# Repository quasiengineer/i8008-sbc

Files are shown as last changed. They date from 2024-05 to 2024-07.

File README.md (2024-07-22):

# System board for Intel 8008

Video about this project:
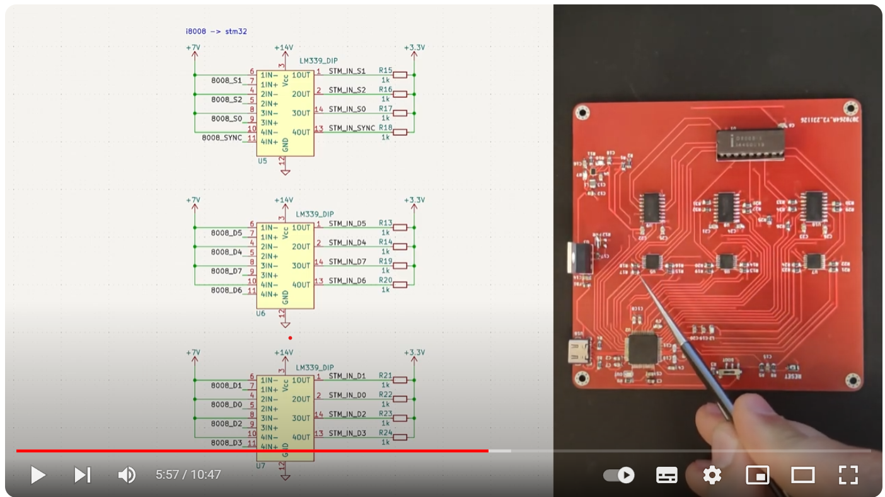
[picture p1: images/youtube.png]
Video about this project (https://www.youtube.com/watch?v=hh_iSX-aM4Q "Video about this project")


## Board

Schematics in [pdf format](./pcb/schematic.pdf)

schematic

Archive with gerber files and drill locations could be found [here](./pcb/manufacturing/manufacturing.zip)

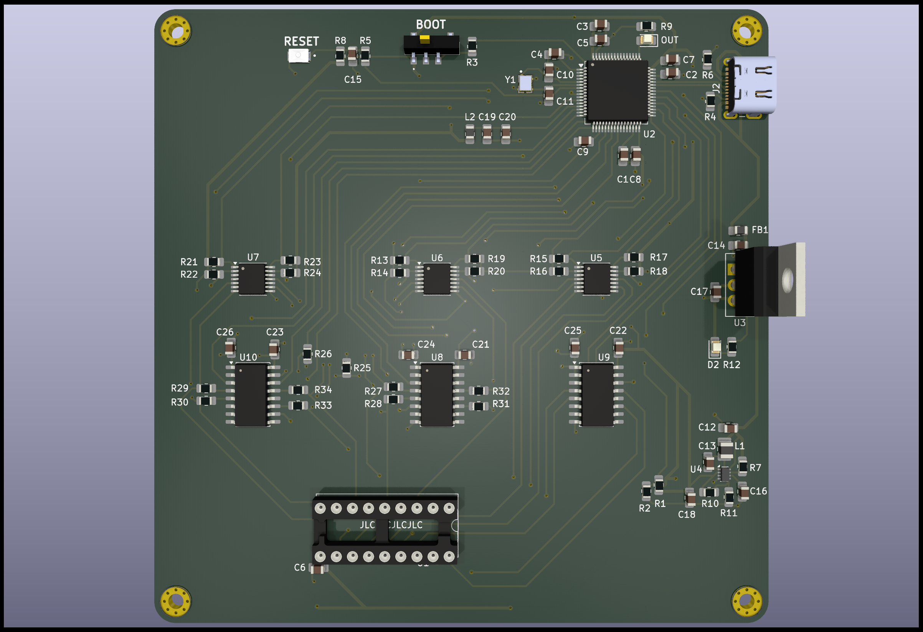
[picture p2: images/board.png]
pcb


Bill of material in [CSV format](./pcb/i8008-sbc.csv)

|Reference |Value |Qty|Mouser Part Number  |
|---|---|---|---|
|C4,C5,C6,C7,C8,C9,C13,C15,C20,C21,C22,C23,C24,C25,C26|100n |15 |187-CL21B104KACNFNC |
|R13,R14,R15,R16,R17,R18,R19,R20,R21,R22,R23,R24 |1k |12 |603-RT0805FRE071KL  |
|R5,R27,R28,R29,R30,R31,R32,R33,R34 |220 |9  |603-RT0805FRE10220RL|
|R1,R2,R3,R8,R25,R26 |10k |6  |603-RT0805FRE1310KL |
|U8,U9,U10 |CD40109B |3  |595-CD40109BNSR |
|U5,U6,U7 |LM339_DIP |3  |595-LM339APWR |
|C14,C16,C19 |1u |3  |187-CL21B105KOFNNNE |
|R7,R11 |30k |2  |603-RT0805FRE0730KL |
|R4,R6 |5k1 |2  |603-RT0805FRE075K1L |
|C17,C18 |10u |2  |810-C2012JB1C106M08C|
|C10,C11 |10p |2  |710-885012007010 |
|C3,C12 |4u7 |2  |810-C2012X5R1C475M0B|
|C1,C2 |2u2 |2  |187-CL21A225KAFNNNG |
|Y1 |16Mhz |1  |520-160-10-36CKM-TR3|
|U4 |MP3438 |1  |946-MP3438GTL-P |
|U3 |LM2937xT |1  |926-LM2937ET-3.3NOPB|
|U2 |STM32H7A3RGTx |1  |511-STM32H7A3RGT6 |
|U1 |Intel 8008 |1  |571-1-2199298-5 |
|SW2 |RESET |1  |667-EVP-AWED4A |
|SW1 |BOOT |1  |113-SS3PMVT/R |
|R12 |2k2 |1  |603-RT0805FRE072K2L |
|R10 |390k |1  |603-RT0805FRE07390KL|
|R9 |4k7 |1  |603-RT0805FRE074K7L |
|L2 |27n |1  |652-CE201210-27NJ |
|L1 |8u2, 800mA |1  |652-SRR1280-8R2Y |
|J2 |Type-C |1  |656-DX07S016JA1R1500|
|FB1 |FerriteBead_Small|1  |652-MH2029-101Y |
|D2 |Green |1  |710-150080VS75000 |
|D1 |Red |1  |710-150080RS75000 |

Also you can find prepared Mouser project [here](https://www.mouser.com/ProjectManager/ProjectDetail.aspx?AccessID=507c82b5f1).

## Firmware

There is compiled [hex file](./firmware/bin/i8008-sbc.hex) in repository, that could be flashed to PCB.

Make sure that `BOOT` switch lever shifted in direction of `RESET` button and connect the board via USB and use stm32 programming software. I am using stm32programmer.

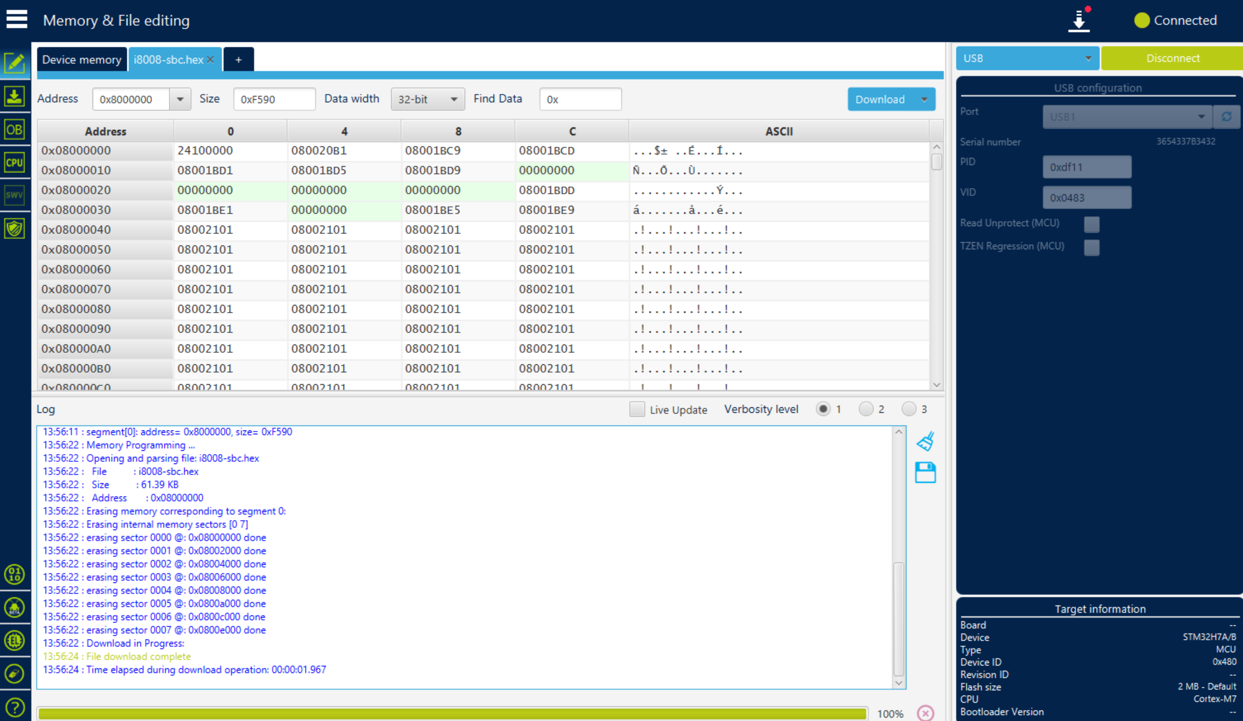
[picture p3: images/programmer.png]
programming


## Software

Make sure that `BOOT` switch lever shifted in direction of stm32 MCU and connect the board via USB.

Red LED should be lighting and new terminal COM device should appear in the system.

To actually run a program in 8008 you just need to run single command:
```sh
node index.js -port=COM5 -rom="programs/blank.i8008"
```

Where `COM5` is the port name. And ROM is the path for program to be run.

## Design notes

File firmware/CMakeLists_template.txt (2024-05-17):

#${templateWarning}
set(CMAKE_SYSTEM_NAME Generic)
set(CMAKE_SYSTEM_VERSION 1)
${cmakeRequiredVersion}
# specify cross-compilers and tools
set(CMAKE_C_COMPILER arm-none-eabi-gcc)
set(CMAKE_CXX_COMPILER arm-none-eabi-g++)
set(CMAKE_ASM_COMPILER  arm-none-eabi-gcc)
set(CMAKE_AR arm-none-eabi-ar)
set(CMAKE_OBJCOPY arm-none-eabi-objcopy)
set(CMAKE_OBJDUMP arm-none-eabi-objdump)
set(SIZE arm-none-eabi-size)
set(CMAKE_TRY_COMPILE_TARGET_TYPE STATIC_LIBRARY)

# project settings
project(${projectName} C CXX ASM)
set(CMAKE_CXX_STANDARD 17)
set(CMAKE_C_STANDARD 11)

#Uncomment for hardware floating point
#add_compile_definitions(ARM_MATH_CM4;ARM_MATH_MATRIX_CHECK;ARM_MATH_ROUNDING)
#add_compile_options(-mfloat-abi=hard -mfpu=fpv4-sp-d16)
#add_link_options(-mfloat-abi=hard -mfpu=fpv4-sp-d16)

#Uncomment for software floating point
#add_compile_options(-mfloat-abi=soft)

add_compile_options(-mcpu=${mcpu} -mthumb -mthumb-interwork)
add_compile_options(-ffunction-sections -fdata-sections -fno-common -fmessage-length=0)

# uncomment to mitigate c++17 absolute addresses warnings
#set(CMAKE_CXX_FLAGS "$${CMAKE_CXX_FLAGS} -Wno-register")

# Enable assembler files preprocessing
add_compile_options($<$<COMPILE_LANGUAGE:ASM>:-x$<SEMICOLON>assembler-with-cpp>)

if ("$${CMAKE_BUILD_TYPE}" STREQUAL "Release")
    message(STATUS "Maximum optimization for speed")
    add_compile_options(-Ofast)
elseif ("$${CMAKE_BUILD_TYPE}" STREQUAL "RelWithDebInfo")
    message(STATUS "Maximum optimization for speed, debug info included")
    add_compile_options(-Ofast -g)
elseif ("$${CMAKE_BUILD_TYPE}" STREQUAL "MinSizeRel")
    message(STATUS "Maximum optimization for size")
    add_compile_options(-Os)
else ()
    message(STATUS "Minimal optimization, debug info included")
    add_compile_options(-Og -g)
endif ()

include_directories(${includes})

add_definitions(${defines})

file(GLOB_RECURSE SOURCES ${sources} "App/*.*")

set(LINKER_SCRIPT $${CMAKE_SOURCE_DIR}/${linkerScript})

add_link_options(-Wl,-gc-sections,--print-memory-usage,-Map=$${PROJECT_BINARY_DIR}/$${PROJECT_NAME}.map)
add_link_options(-mcpu=${mcpu} -mthumb -mthumb-interwork)
add_link_options(-T $${LINKER_SCRIPT})

add_executable($${PROJECT_NAME}.elf $${SOURCES} $${LINKER_SCRIPT})

set(HEX_FILE $${PROJECT_BINARY_DIR}/$${PROJECT_NAME}.hex)
set(BIN_FILE $${PROJECT_BINARY_DIR}/$${PROJECT_NAME}.bin)

add_custom_command(TARGET $${PROJECT_NAME}.elf POST_BUILD
        COMMAND $${CMAKE_OBJCOPY} -Oihex $<TARGET_FILE:$${PROJECT_NAME}.elf> $${HEX_FILE}
        COMMAND $${CMAKE_OBJCOPY} -Obinary $<TARGET_FILE:$${PROJECT_NAME}.elf> $${BIN_FILE}
        COMMENT "Building $${HEX_FILE}
Building $${BIN_FILE}")

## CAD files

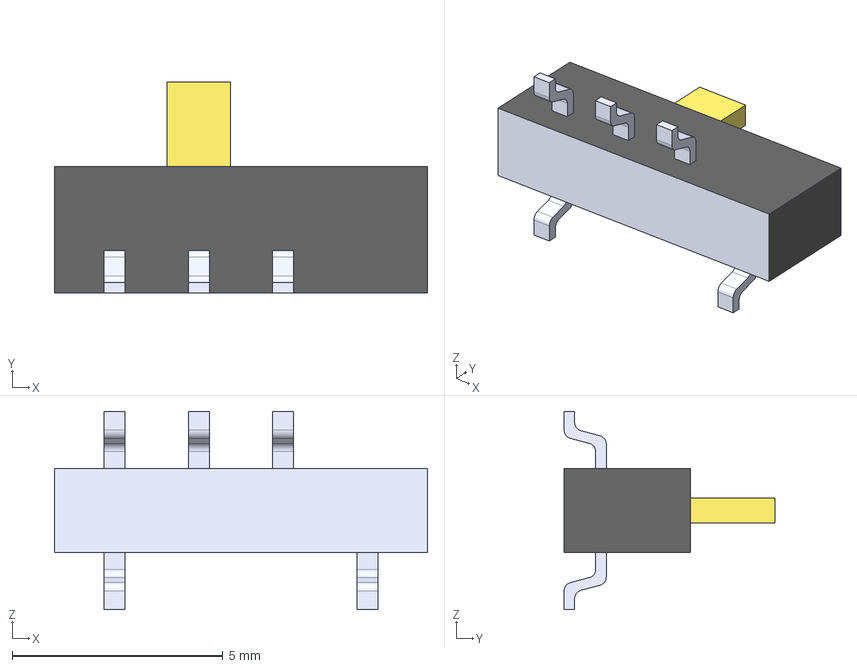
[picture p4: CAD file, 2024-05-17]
pcb/components/3d/SS3NP-MS-colors.STEP
8.85 x 5.00 x 4.70 mm
SS3NP-MS
SS3NP-MS001
SS3NP-MS002
SS3NP-MS003
SS3NP-MS004
SS3NP-MS005
SS3NP-MS006

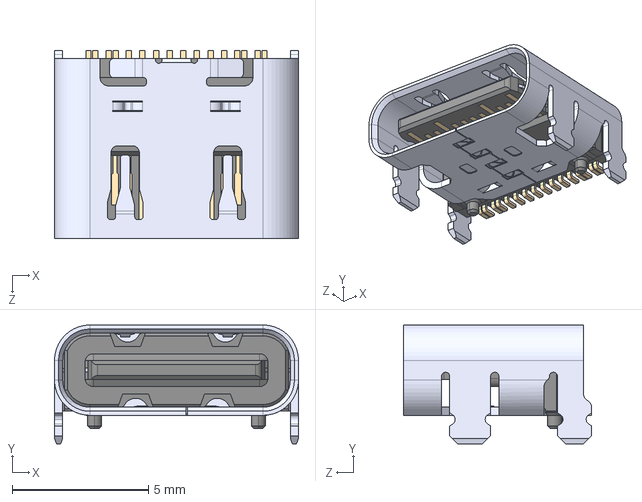
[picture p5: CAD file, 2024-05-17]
pcb/models/DX07S016JA1R1500.stp
8.94 x 4.36 x 6.90 mm

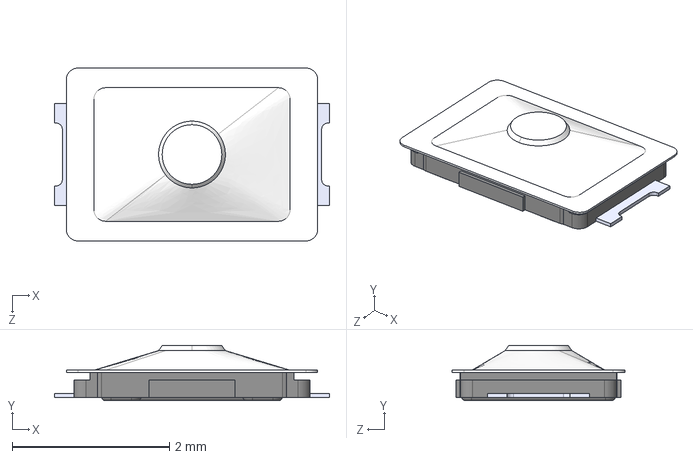
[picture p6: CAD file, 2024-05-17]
pcb/components/3d/EVP-AWED4A.step
3.50 x 0.7 x 2.20 mm

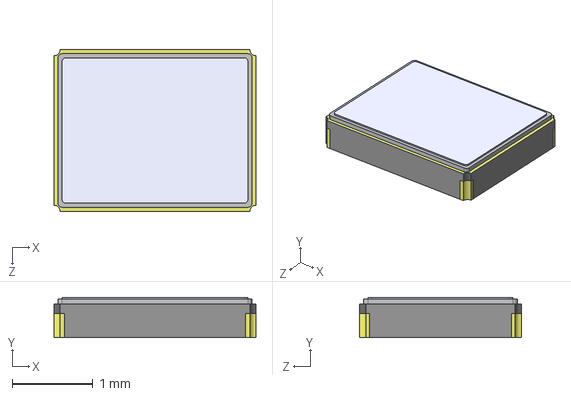
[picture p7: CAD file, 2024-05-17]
pcb/components/3d/ECS-160-10-36-CKM-TR3.step
2.50 x 0.5 x 2.00 mm

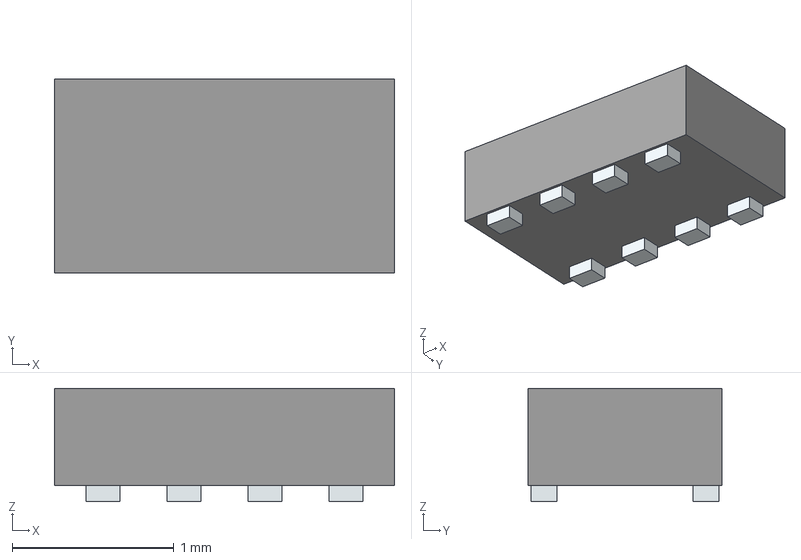
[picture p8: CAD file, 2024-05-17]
pcb/components/3d/MP3438GTL-P.stp
2.10 x 1.20 x 0.7 mm
Pins

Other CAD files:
pcb/components/3d/SS3NP-MS.SLDPRT

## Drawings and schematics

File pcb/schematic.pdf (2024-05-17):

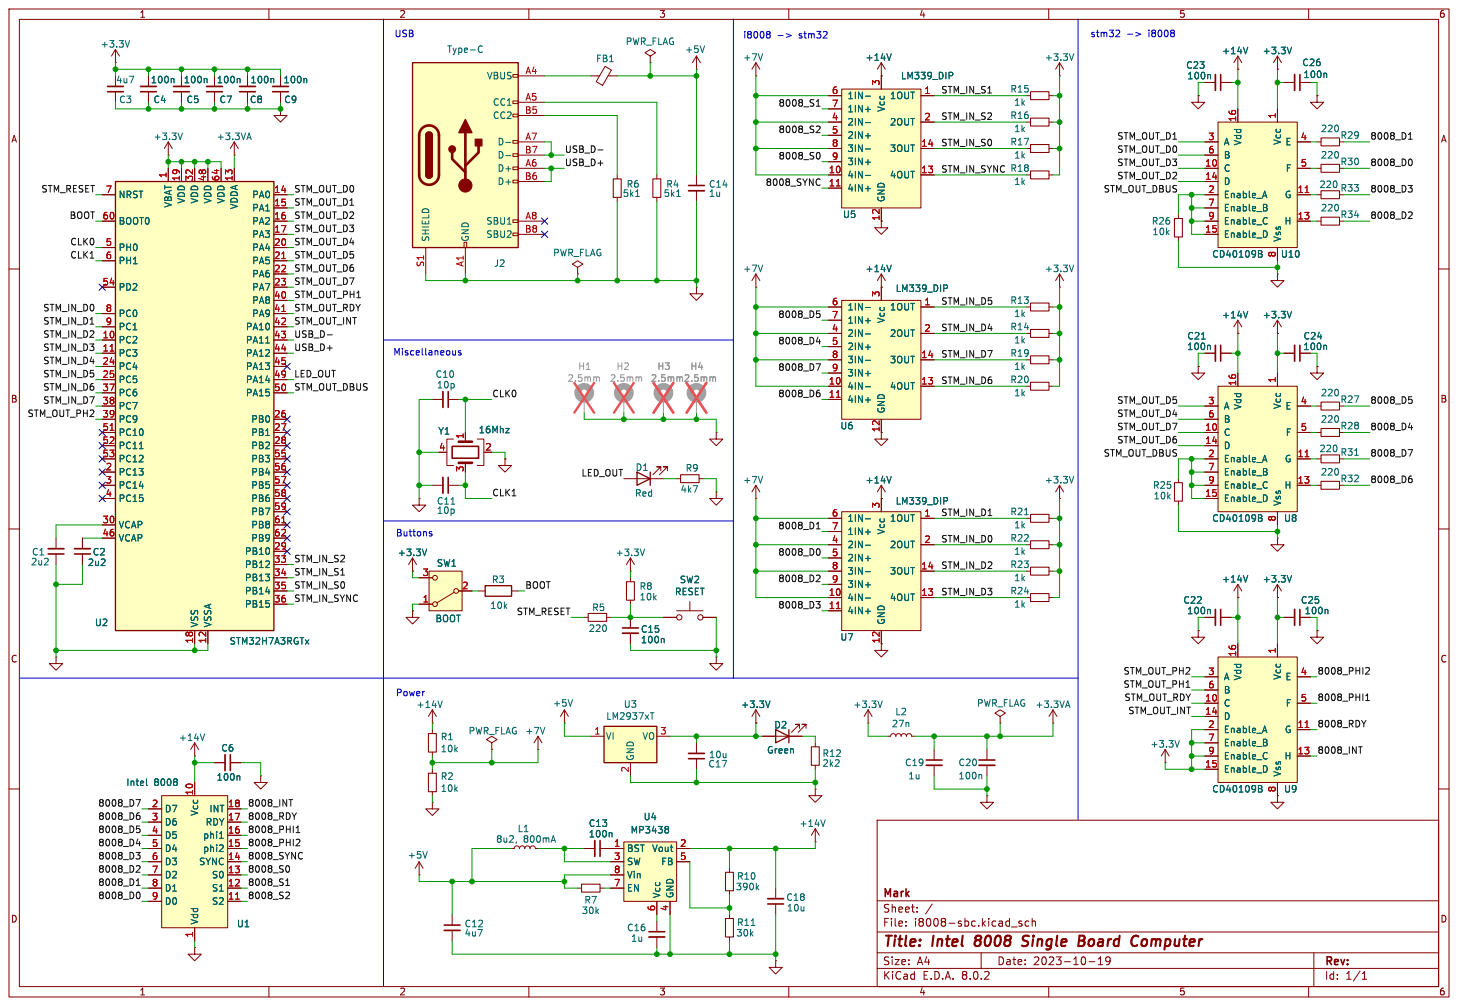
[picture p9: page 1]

1 PC2 10 PC3 11 VSSA 12 VDDA 13 PA0 14 PA1 15 PA2 16 PA3 17 VSS 18 VDD 19 PC13 2 PA4 20 PA5 21 PA6 22 PA7 23 PC4 24 PC5 25 PB0 26 PB1 27 PB2 28 PB10 29 PC14 3 VCAP 30 VDD 32 PB12 33 PB13 34 PB14 35 PB15 36 PC6 37 PC7 38 PC9 39 PC15 4 PA8 40 PA9 41 PA10 42 PA11 43 PA12 44 PA13 45 VCAP 46 VDD 48 PA14 49 PH0 5 PA15 50 PC10 51 PC11 52 PC12 53 PD2 54 PB3 55 PB4 56 PB5 57 PB6 58 PB7 59 PH1 6 BOOT0 60 PB8 61 PB9 62 VDD 64 NRST 7 PC0 8 PC1 9 C9

1 PC2 10 PC3 11 VSSA 12 VDDA 13 PA0 14 PA1 15 PA2 16 PA3 17 VSS 18 VDD 19 PC13 2 PA4 20 PA5 21 PA6 22 PA7 23 PC4 24 PC5 25 PB0 26 PB1 27 PB2 28 PB10 29 PC14 3 VCAP 30 VDD 32 PB12 33 PB13 34 PB14 35 PB15 36 PC6 37 PC7 38 PC9 39 PC15 4 PA8 40 PA9 41 PA10 42 PA11 43 PA12 44 PA13 45 VCAP 46 VDD 48 PA14 49 PH0 5 PA15 50 PC10 51 PC11 52 PC12 53 PD2 54 PB3 55 PB4 56 PB5 57 PB6 58 PB7 59 PH1 6 BOOT0 60 PB8 61 PB9 62 VDD 64 NRST 7 PC0 8 PC1 9 U2 STM32H7A3RGTx

4 FB 5 Vcc 6 EN 7 Vin 8 SW1 BOOT

4 FB 5 Vcc 6 EN 7 Vin 8 U4 MP3438 C16

Id: 1/1 Title: Intel 8008 Single Board Computer File: i8008-sbc.kicad_sch Sheet: / Mark

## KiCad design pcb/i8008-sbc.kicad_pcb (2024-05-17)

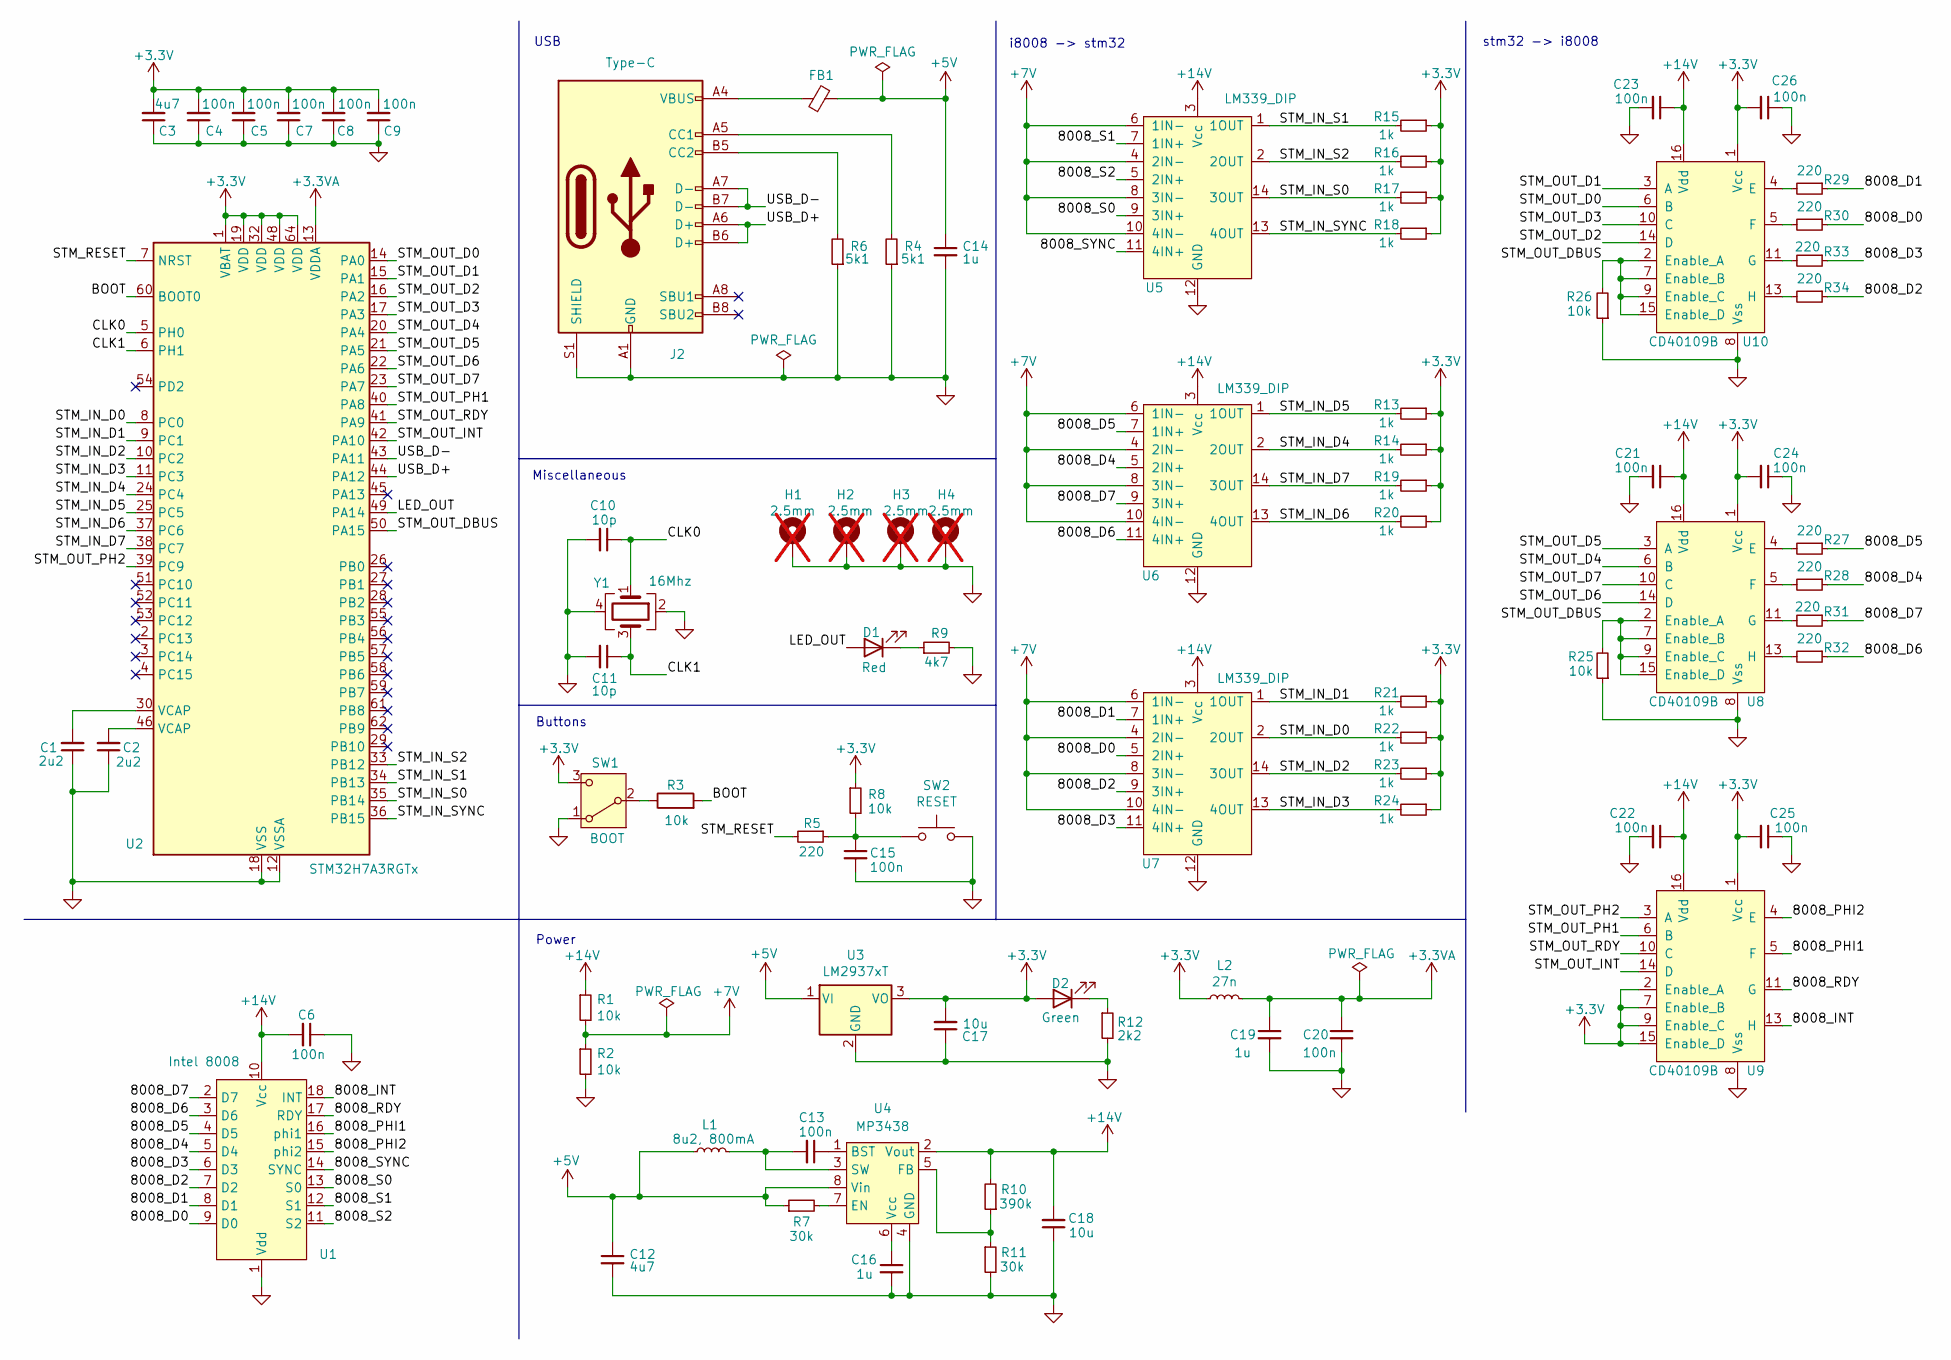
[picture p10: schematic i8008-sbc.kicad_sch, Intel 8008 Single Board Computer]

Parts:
C1, C2: 2u2; C_0805_2012Metric_Pad1.18x1.45mm_HandSolder; Mouser Part Number 187-CL21A225KAFNNNG
C3, C12: 4u7; C_0805_2012Metric_Pad1.18x1.45mm_HandSolder; Mouser Part Number 810-C2012X5R1C475M0B
C4, C5, C6, C7, C8, C9, C13, C15, C20, C21, C22, C23, C24, C25, C26: 100n; C_0805_2012Metric_Pad1.18x1.45mm_HandSolder; Mouser Part Number 187-CL21B104KACNFNC
C10, C11: 10p; C_0805_2012Metric_Pad1.18x1.45mm_HandSolder; Mouser Part Number 710-885012007010
C14, C16, C19: 1u; C_0805_2012Metric_Pad1.18x1.45mm_HandSolder; Mouser Part Number 187-CL21B105KOFNNNE
C17, C18: 10u; C_0805_2012Metric_Pad1.18x1.45mm_HandSolder; Mouser Part Number 810-C2012JB1C106M08C
D1: Red; LED_0805_2012Metric_Pad1.15x1.40mm_HandSolder; Mouser Part Number 710-150080RS75000
D2: Green; LED_0805_2012Metric_Pad1.15x1.40mm_HandSolder; Mouser Part Number 710-150080VS75000
FB1: FerriteBead_Small; L_0805_2012Metric_Pad1.15x1.40mm_HandSolder; Mouser Part Number 652-MH2029-101Y
H1, H2, H3, H4: 2.5mm; MountingHole_2.5mm_Pad_Via; not fitted
J2: Type-C; USB_C_Receptacle_JAE_DX07S016JA1R1500; Mouser Part Number 656-DX07S016JA1R1500
L1: 8u2, 800mA; L_1008_2520Metric_Pad1.43x2.20mm_HandSolder; Mouser Part Number 652-SRR1280-8R2Y
L2: 27n; L_0805_2012Metric_Pad1.15x1.40mm_HandSolder; Mouser Part Number 652-CE201210-27NJ
R1, R2, R3, R8, R25, R26: 10k; R_0805_2012Metric_Pad1.20x1.40mm_HandSolder; Mouser Part Number 603-RT0805FRE1310KL
R4, R6: 5k1; R_0805_2012Metric_Pad1.20x1.40mm_HandSolder; Mouser Part Number 603-RT0805FRE075K1L
R5, R27, R28, R29, R30, R31, R32, R33, R34: 220; R_0805_2012Metric_Pad1.20x1.40mm_HandSolder; Mouser Part Number 603-RT0805FRE10220RL
R7, R11: 30k; R_0805_2012Metric_Pad1.20x1.40mm_HandSolder; Mouser Part Number 603-RT0805FRE0730KL
R9: 4k7; R_0805_2012Metric_Pad1.20x1.40mm_HandSolder; Mouser Part Number 603-RT0805FRE074K7L
R10: 390k; R_0805_2012Metric_Pad1.20x1.40mm_HandSolder; Mouser Part Number 603-RT0805FRE07390KL
R12: 2k2; R_0805_2012Metric_Pad1.20x1.40mm_HandSolder; Mouser Part Number 603-RT0805FRE072K2L
R13, R14, R15, R16, R17, R18, R19, R20, R21, R22, R23, R24: 1k; R_0805_2012Metric_Pad1.20x1.40mm_HandSolder; Mouser Part Number 603-RT0805FRE071KL
SW1: BOOT; SS3NPMSVTR; Mouser Part Number 113-SS3PMVT/R
SW2: RESET; EVPAWCD4A; Mouser Part Number 667-EVP-AWED4A
U1: Intel 8008; DIP-18_W7.62mm_Socket; Mouser Part Number 571-1-2199298-5
U2: STM32H7A3RGTx; LQFP-64_10x10mm_P0.5mm; Mouser Part Number 511-STM32H7A3RGT6
U3: LM2937xT; TO-220-3_Vertical; Mouser Part Number 926-LM2937ET-3.3NOPB
U4: MP3438; SOT-583-8; Mouser Part Number 946-MP3438GTL-P
U5, U6, U7: LM339_DIP; TSSOP-14_4.4x5mm_P0.65mm; Mouser Part Number 595-LM339APWR
U8, U9, U10: CD40109B; SO-16_5.3x10.2mm_P1.27mm; Mouser Part Number 595-CD40109BNSR
Y1: 16Mhz; XTAL_ECS-160-10-36-CKM-TR3; Mouser Part Number 520-160-10-36CKM-TR3

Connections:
+3.3V: C3.2, C4.2, C5.2, C7.2, C8.2, C9.2, C17.2, C24.2, C25.2, C26.2, D2.2 (A), L2.1, R8.1, R13.1, R14.1, R15.1, R16.1, R17.1, R18.1, R19.1, R20.1, R21.1, R22.1, R23.1, R24.1, SW1.3 (C), U2.1 (VBAT), U2.19 (VDD), U2.32 (VDD), U2.48 (VDD), U2.64 (VDD), U3.3 (VO), U8.1 (Vcc), U9.1 (Vcc), U9.2 (Enable_A), U9.7 (Enable_B), U9.9 (Enable_C), U9.15 (Enable_D), U10.1 (Vcc)
+3.3VA: C19.1, C20.1, L2.2, U2.13 (VDDA)
+5V: C12.1, C14.1, FB1.2, L1.1, R7.1, U3.1 (VI), U4.8 (Vin)
+7V: R1.2, R2.1, U5.4 (2IN-), U5.6 (1IN-), U5.8 (3IN-), U5.10 (4IN-), U6.4 (2IN-), U6.6 (1IN-), U6.8 (3IN-), U6.10 (4IN-), U7.4 (2IN-), U7.6 (1IN-), U7.8 (3IN-), U7.10 (4IN-)
+14V: C6.2, C18.2, C21.1, C22.1, C23.1, R1.1, R10.2, U1.10 (Vcc), U4.2 (Vout), U5.3 (Vcc), U6.3 (Vcc), U7.3 (Vcc), U8.16 (Vdd), U9.16 (Vdd), U10.16 (Vdd)
/8008_D0: R30.1, U1.9 (D0), U7.5 (2IN+)
/8008_D1: R29.1, U1.8 (D1), U7.7 (1IN+)
/8008_D2: R34.1, U1.7 (D2), U7.9 (3IN+)
/8008_D3: R33.1, U1.6 (D3), U7.11 (4IN+)
/8008_D4: R28.1, U1.5 (D4), U6.5 (2IN+)
/8008_D5: R27.1, U1.4 (D5), U6.7 (1IN+)
/8008_D6: R32.1, U1.3 (D6), U6.11 (4IN+)
/8008_D7: R31.1, U1.2 (D7), U6.9 (3IN+)
/8008_INT: U1.18 (INT), U9.13 (H)
/8008_PHI1: U1.16 (phi1), U9.5 (F)
/8008_PHI2: U1.15 (phi2), U9.4 (E)
/8008_RDY: U1.17 (RDY), U9.11 (G)
/8008_S0: U1.13 (S0), U5.9 (3IN+)
/8008_S1: U1.12 (S1), U5.7 (1IN+)
/8008_S2: U1.11 (S2), U5.5 (2IN+)
/8008_SYNC: U1.14 (SYNC), U5.11 (4IN+)
/BOOT: R3.2, U2.60 (BOOT0)
/CLK0: C10.1, U2.5 (PH0), Y1.1
/CLK1: C11.1, U2.6 (PH1), Y1.3
/LED_OUT: D1.2 (A), U2.49 (PA14)
/STM_IN_D0: R22.2, U2.8 (PC0), U7.2 (2OUT)
/STM_IN_D1: R21.2, U2.9 (PC1), U7.1 (1OUT)
/STM_IN_D2: R23.2, U2.10 (PC2), U7.14 (3OUT)
/STM_IN_D3: R24.2, U2.11 (PC3), U7.13 (4OUT)
/STM_IN_D4: R14.2, U2.24 (PC4), U6.2 (2OUT)
/STM_IN_D5: R13.2, U2.25 (PC5), U6.1 (1OUT)
/STM_IN_D6: R20.2, U2.37 (PC6), U6.13 (4OUT)
/STM_IN_D7: R19.2, U2.38 (PC7), U6.14 (3OUT)
/STM_IN_S0: R17.2, U2.35 (PB14), U5.14 (3OUT)
/STM_IN_S1: R15.2, U2.34 (PB13), U5.1 (1OUT)
/STM_IN_S2: R16.2, U2.33 (PB12), U5.2 (2OUT)
/STM_IN_SYNC: R18.2, U2.36 (PB15), U5.13 (4OUT)
/STM_OUT_D0: U2.14 (PA0), U10.6 (B)
/STM_OUT_D1: U2.15 (PA1), U10.3 (A)
/STM_OUT_D2: U2.16 (PA2), U10.14 (D)
/STM_OUT_D3: U2.17 (PA3), U10.10 (C)
/STM_OUT_D4: U2.20 (PA4), U8.6 (B)
/STM_OUT_D5: U2.21 (PA5), U8.3 (A)
/STM_OUT_D6: U2.22 (PA6), U8.14 (D)
/STM_OUT_D7: U2.23 (PA7), U8.10 (C)
/STM_OUT_DBUS: R25.2, R26.2, U2.50 (PA15), U8.2 (Enable_A), U8.7 (Enable_B), U8.9 (Enable_C), U8.15 (Enable_D), U10.2 (Enable_A), U10.7 (Enable_B), U10.9 (Enable_C), U10.15 (Enable_D)
/STM_OUT_INT: U2.42 (PA10), U9.14 (D)
/STM_OUT_PH1: U2.40 (PA8), U9.6 (B)
/STM_OUT_PH2: U2.39 (PC9), U9.3 (A)
/STM_OUT_RDY: U2.41 (PA9), U9.10 (C)
/STM_RESET: R5.2, U2.7 (NRST)
/USB_D+: J2.A6 (D+), J2.B6 (D+), U2.44 (PA12)
/USB_D-: J2.A7 (D-), J2.B7 (D-), U2.43 (PA11)
GND: C1.1, C2.1, C3.1, C4.1, C5.1, C6.1, C7.1, C8.1, C9.1, C10.2, C11.2, C12.2, C14.2, C15.2, C16.2, C17.1, C18.1, C19.2, C20.2, C21.2, C22.2, C23.2, C24.1, C25.1, C26.1, H1.1, H2.1, H3.1, H4.1, J2.A1 (GND), J2.A12 (GND), J2.B1 (GND), J2.B12 (GND), J2.S1 (SHIELD), R2.2, R4.1, R6.1, R9.2, R11.2, R12.2, R25.1, R26.1, SW1.1 (A), SW2.2, U1.1 (Vdd), U2.12 (VSSA), U2.18 (VSS), U2.31 (VSS), U2.47 (VSS), U2.63 (VSS), U3.2 (GND), U4.4 (GND), U5.12 (GND), U6.12 (GND), U7.12 (GND), U8.8 (Vss), U9.8 (Vss), U10.8 (Vss), Y1.2, Y1.4
unnamed: C1.2, U2.30 (VCAP)
unnamed: C2.2, U2.46 (VCAP)
unnamed: C15.1, R5.1, R8.2, SW2.1
unnamed: D1.1 (K), R9.1
unnamed: D2.1 (K), R12.1
unnamed: FB1.1, J2.A4 (VBUS), J2.A9 (VBUS), J2.B4 (VBUS), J2.B9 (VBUS)
unnamed: J2.A5 (CC1), R4.2
unnamed: J2.B5 (CC2), R6.2
unnamed: R3.1, SW1.2 (B)
unnamed: C13.1, U4.1 (BST)
unnamed: R7.2, U4.7 (EN)
unnamed: R10.1, R11.1, U4.5 (FB)
unnamed: C13.2, L1.2, U4.3 (SW)
unnamed: C16.1, U4.6 (Vcc)
unnamed: R27.2, U8.4 (E)
unnamed: R28.2, U8.5 (F)
unnamed: R31.2, U8.11 (G)
unnamed: R32.2, U8.13 (H)
unnamed: R29.2, U10.4 (E)
unnamed: R30.2, U10.5 (F)
unnamed: R33.2, U10.11 (G)
unnamed: R34.2, U10.13 (H)

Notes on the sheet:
Buttons
i8008 -> stm32
USB
Power
stm32 -> i8008
Miscellaneous

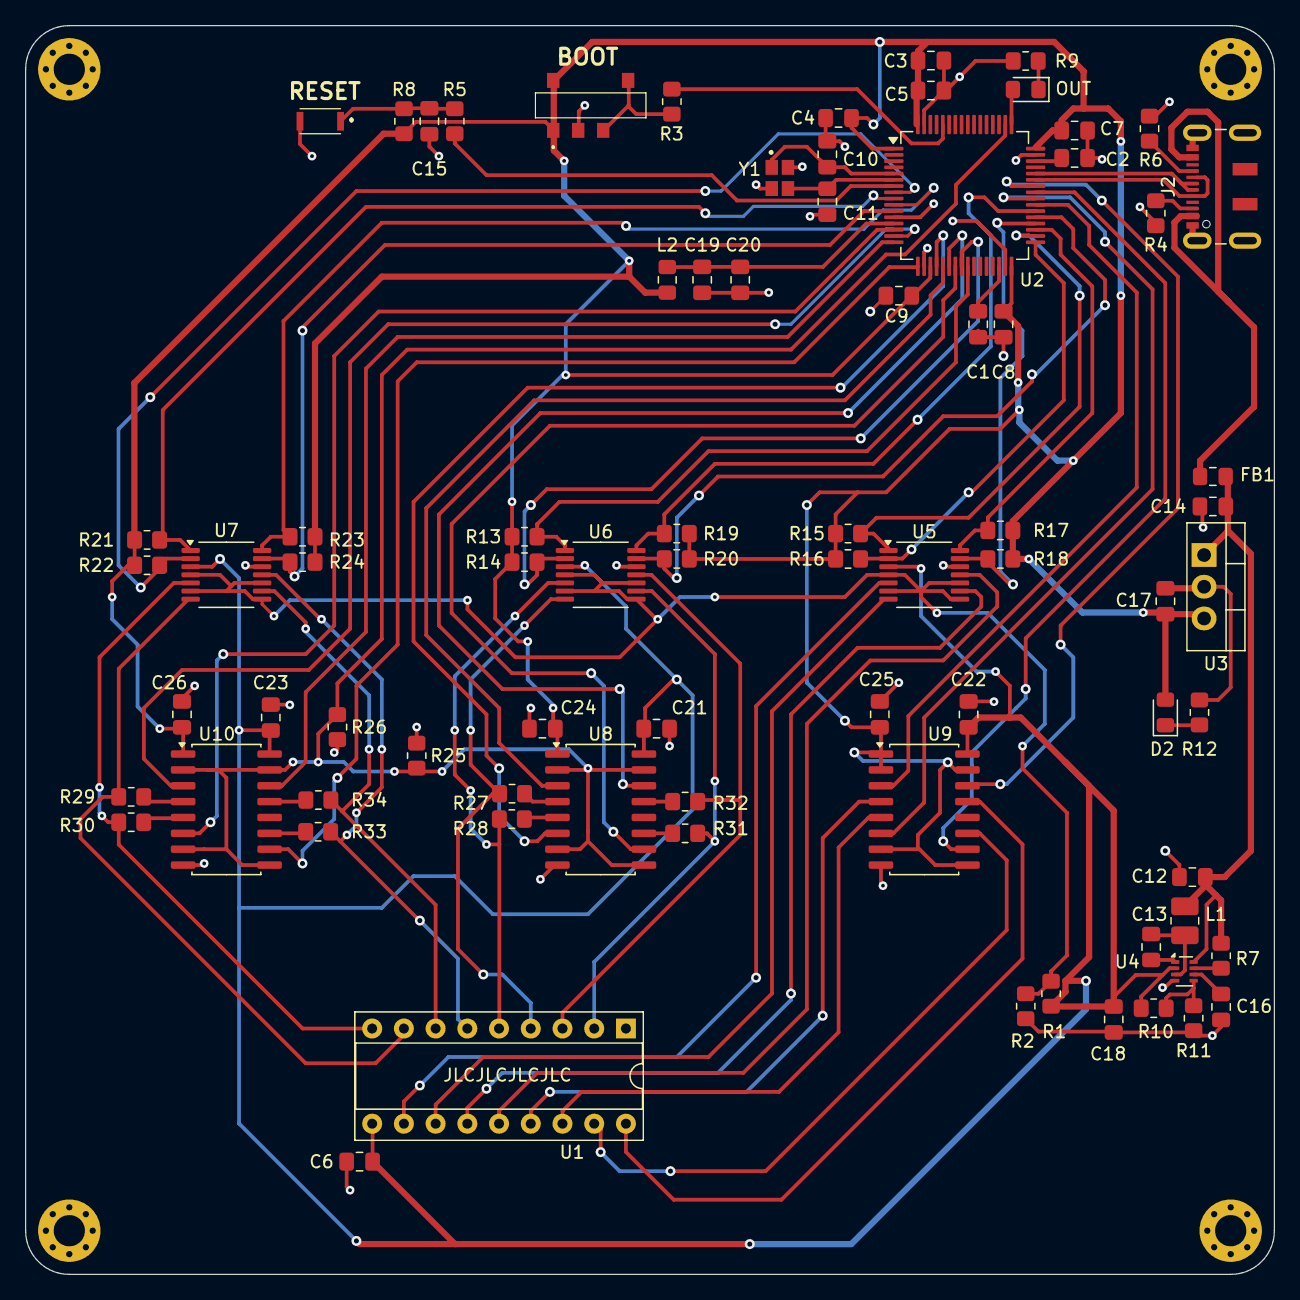
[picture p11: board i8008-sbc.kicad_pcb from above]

Board: 2 copper layers, 100.0 x 100.0 mm, 83 parts (0 on the bottom side), 76 nets.

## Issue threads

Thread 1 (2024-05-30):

a comment

MarioPieschel, 2024-05-30:
Your board is technically very good, really. But it is not cool.
Ask yourself, what do you want to do with this board?
Is it going to end up in the big craft box at some point?

Make it cool:
Add LEDs for data, address and control buses, just like an old computer.
Build a cool case for your board. Be creative!
Write cool programs for the i8008. Or maybe a small C-Cross compiler for the i8008?

I'm looking forward to seeing your results.

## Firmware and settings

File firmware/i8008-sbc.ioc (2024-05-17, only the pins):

Mcu.UserName=STM32H7A3RGTx
PA0.GPIO_Label=STM_OUT_D0
PA0.Signal=GPIO_Output
PA1.GPIO_Label=STM_OUT_D1
PA1.Signal=GPIO_Output
PA10.GPIO_Label=STM_OUT_INT
PA10.Signal=GPIO_Output
PA11.Signal=USB_OTG_HS_DM
PA12.Signal=USB_OTG_HS_DP
PA14.GPIO_Label=LED_OUT
PA14.Signal=GPIO_Output
PA15.GPIO_Label=STM_OUT_DBUS
PA15.Signal=GPIO_Output
PA2.GPIO_Label=STM_OUT_D2
PA2.Signal=GPIO_Output
PA3.GPIO_Label=STM_OUT_D3
PA3.Signal=GPIO_Output
PA4.GPIO_Label=STM_OUT_D4
PA4.Signal=GPIO_Output
PA5.GPIO_Label=STM_OUT_D5
PA5.Signal=GPIO_Output
PA6.GPIO_Label=STM_OUT_D6
PA6.Signal=GPIO_Output
PA7.GPIO_Label=STM_OUT_D7
PA7.Signal=GPIO_Output
PA8.GPIO_Label=STM_OUT_PH1
PA8.Signal=S_TIM1_CH1
PA9.GPIO_Label=STM_OUT_RDY
PA9.Signal=GPIO_Output
PB12.GPIO_Label=STM_IN_S2
PB12.Signal=GPIO_Input
PB13.GPIO_Label=STM_IN_S1
PB13.Signal=GPIO_Input
PB14.GPIO_Label=STM_IN_S0
PB14.Signal=GPIO_Input
PB15.GPIO_Label=STM_IN_SYNC
PB15.Signal=GPIO_Input
PB5.GPIO_Label=TEST1
PB5.Signal=GPIO_Output
PC0.GPIO_Label=STM_IN_D0
PC0.Signal=GPIO_Input
PC1.GPIO_Label=STM_IN_D1
PC1.Signal=GPIO_Input
PC2.GPIO_Label=STM_IN_D2
PC2.Signal=GPIO_Input
PC3.GPIO_Label=STM_IN_D3
PC3.Signal=GPIO_Input
PC4.GPIO_Label=STM_IN_D4
PC4.Signal=GPIO_Input
PC5.GPIO_Label=STM_IN_D5
PC5.Signal=GPIO_Input
PC6.GPIO_Label=STM_IN_D6
PC6.Signal=GPIO_Input
PC7.GPIO_Label=STM_IN_D7
PC7.Signal=GPIO_Input
PC9.GPIO_Label=STM_OUT_PH2
PC9.Signal=S_TIM8_CH4
PD2.GPIO_Label=TEST2
PD2.Signal=GPIO_Output
PH0-OSC_IN.Signal=RCC_OSC_IN
PH1-OSC_OUT.Signal=RCC_OSC_OUT

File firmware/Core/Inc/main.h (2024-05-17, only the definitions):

#define STM_IN_D0_Pin GPIO_PIN_0
#define STM_IN_D0_GPIO_Port GPIOC
#define STM_IN_D1_Pin GPIO_PIN_1
#define STM_IN_D1_GPIO_Port GPIOC
#define STM_IN_D2_Pin GPIO_PIN_2
#define STM_IN_D2_GPIO_Port GPIOC
#define STM_IN_D3_Pin GPIO_PIN_3
#define STM_IN_D3_GPIO_Port GPIOC
#define STM_OUT_D0_Pin GPIO_PIN_0
#define STM_OUT_D0_GPIO_Port GPIOA
#define STM_OUT_D1_Pin GPIO_PIN_1
#define STM_OUT_D1_GPIO_Port GPIOA
#define STM_OUT_D2_Pin GPIO_PIN_2
#define STM_OUT_D2_GPIO_Port GPIOA
#define STM_OUT_D3_Pin GPIO_PIN_3
#define STM_OUT_D3_GPIO_Port GPIOA
#define STM_OUT_D4_Pin GPIO_PIN_4
#define STM_OUT_D4_GPIO_Port GPIOA
#define STM_OUT_D5_Pin GPIO_PIN_5
#define STM_OUT_D5_GPIO_Port GPIOA
#define STM_OUT_D6_Pin GPIO_PIN_6
#define STM_OUT_D6_GPIO_Port GPIOA
#define STM_OUT_D7_Pin GPIO_PIN_7
#define STM_OUT_D7_GPIO_Port GPIOA
#define STM_IN_D4_Pin GPIO_PIN_4
#define STM_IN_D4_GPIO_Port GPIOC
#define STM_IN_D5_Pin GPIO_PIN_5
#define STM_IN_D5_GPIO_Port GPIOC
#define STM_IN_S2_Pin GPIO_PIN_12
#define STM_IN_S2_GPIO_Port GPIOB
#define STM_IN_S1_Pin GPIO_PIN_13
#define STM_IN_S1_GPIO_Port GPIOB
#define STM_IN_S0_Pin GPIO_PIN_14
#define STM_IN_S0_GPIO_Port GPIOB
#define STM_IN_SYNC_Pin GPIO_PIN_15
#define STM_IN_SYNC_GPIO_Port GPIOB
#define STM_IN_D6_Pin GPIO_PIN_6
#define STM_IN_D6_GPIO_Port GPIOC
#define STM_IN_D7_Pin GPIO_PIN_7
#define STM_IN_D7_GPIO_Port GPIOC
#define STM_OUT_PH2_Pin GPIO_PIN_9
#define STM_OUT_PH2_GPIO_Port GPIOC
#define STM_OUT_PH1_Pin GPIO_PIN_8
#define STM_OUT_PH1_GPIO_Port GPIOA
#define STM_OUT_RDY_Pin GPIO_PIN_9
#define STM_OUT_RDY_GPIO_Port GPIOA
#define STM_OUT_INT_Pin GPIO_PIN_10
#define STM_OUT_INT_GPIO_Port GPIOA
#define LED_OUT_Pin GPIO_PIN_14
#define LED_OUT_GPIO_Port GPIOA
#define STM_OUT_DBUS_Pin GPIO_PIN_15
#define STM_OUT_DBUS_GPIO_Port GPIOA
#define TEST2_Pin GPIO_PIN_2
#define TEST2_GPIO_Port GPIOD
#define TEST1_Pin GPIO_PIN_5
#define TEST1_GPIO_Port GPIOB

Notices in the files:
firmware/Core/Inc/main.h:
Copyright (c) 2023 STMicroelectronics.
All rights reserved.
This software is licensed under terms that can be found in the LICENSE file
